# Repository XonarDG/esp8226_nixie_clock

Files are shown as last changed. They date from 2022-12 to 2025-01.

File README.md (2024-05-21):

# esp8266_nixie_clock

Simple Nixie Clock with an ESP8266 development board

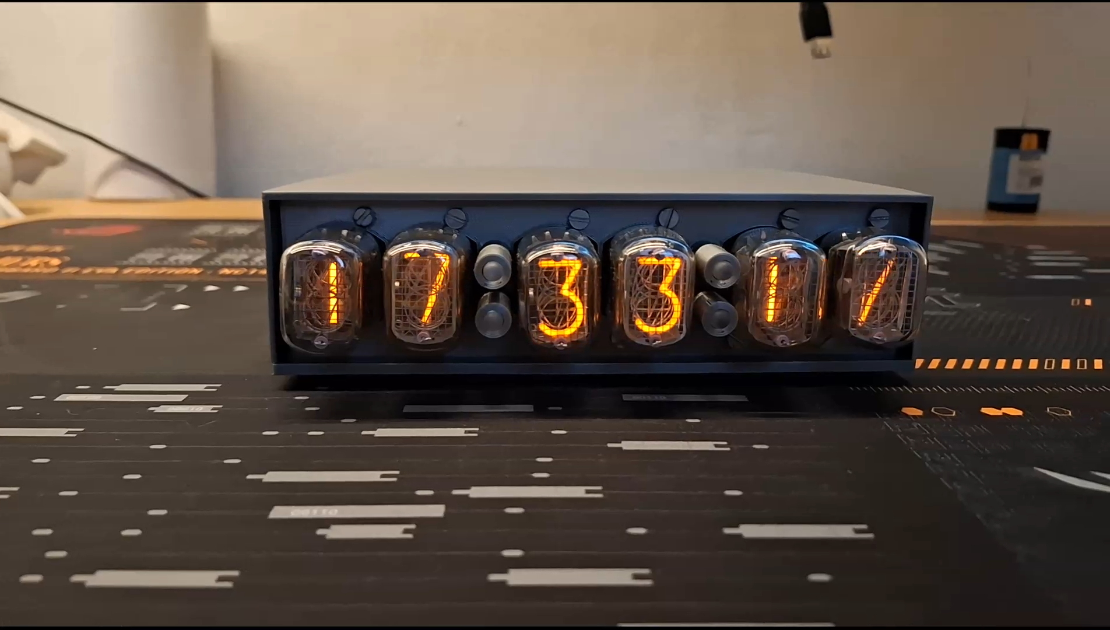
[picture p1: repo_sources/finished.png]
picture of the completed project


## Info

This is a small project for a simple nixie clock using a ESP8266 development board. **WIP! USE AS REFERENCE ONLY!**

## Why?
Like many others, I've fallen for the look of nixies way before this project began. At the time I thought I wasn't capable of a project like this, but in late 2021 I made my first prototype using MH74141 and Tesla ZM1020 nixies. It was rough, didn't work properly and was on a protoboard, but it motivated me into doing more.

In 2024 I made the decision to make this my high school graduation project and this is what came out of it. It still has rough edges here and there, but it works, and it has a somewhat complete enclosure.

At this point I thought it would be a nice touch making the project publicly available. That said its far from done, and I would not recommend making this project on your own.

## Parts
Name | Designation | #
--- | --- | ---
MCU | Wemos D1 Mini | 1
RTC module | generic DS3231 | 1
Shift Register | 74HC595 | 3
Cathode transistors | MPSA42 | 10
Anode optoucouplers | TLP627 | 6
Voltage Regulator | AMS1117 3.3 | 1
Resistor | various values | 26
Pin header (male) | generic 2.54mm | 21
Pin header (famale) | generic 2.54mm | 46

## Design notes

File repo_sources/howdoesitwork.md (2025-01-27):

# How does it work?
This is a file that will explain how the clock works in detail, I might make this into separate files later on.

## Prequisits
Before we start talking about all the principles that allow this clock to work, its important that we set and define certain properties and goals of this project.

### The goal
The goal of this projct is to make a simple, easily modifiable nixie tube clock. In other words, im gonna try to use as little components as possible, while using ones that are readily available and ones that are easy to work with and allow for further modifications.
### Features and properties
1. 6 digits
* Since I've made a 4 digit clock before, I can tell you that watching the same 4 digits for a minute straight is nothing fun. A added benefit is that we can also show other interesing numbers. 
2. NTP synchronization and RTC
* The most common way of keeping somewhat precise time is by utilizing a RTC module, which keeps time using a dedicated IC powered by a battery (usually a CR2023 or similar). This is, relatively speaking, a accurate way of keeping time, but I personaly find these cheap modules too imprecise. I've measured a time delay of around 7 seconds per day, which isn't perticularly bad, but since we're using 6 digits I thought it would be rather nice to have a clock that would be constantly accurate over long periods of time. This is exactly why I decided that I want to synchronize with an NTP server.
3. Extra IO and simplicity
* Yes, I could've used a cheaper discrete MCU. Yes, I could've used SMD versions of IC's to make the footprint smaller. Of course, but that would make the project unfriendly for anyone wishing to modify it.

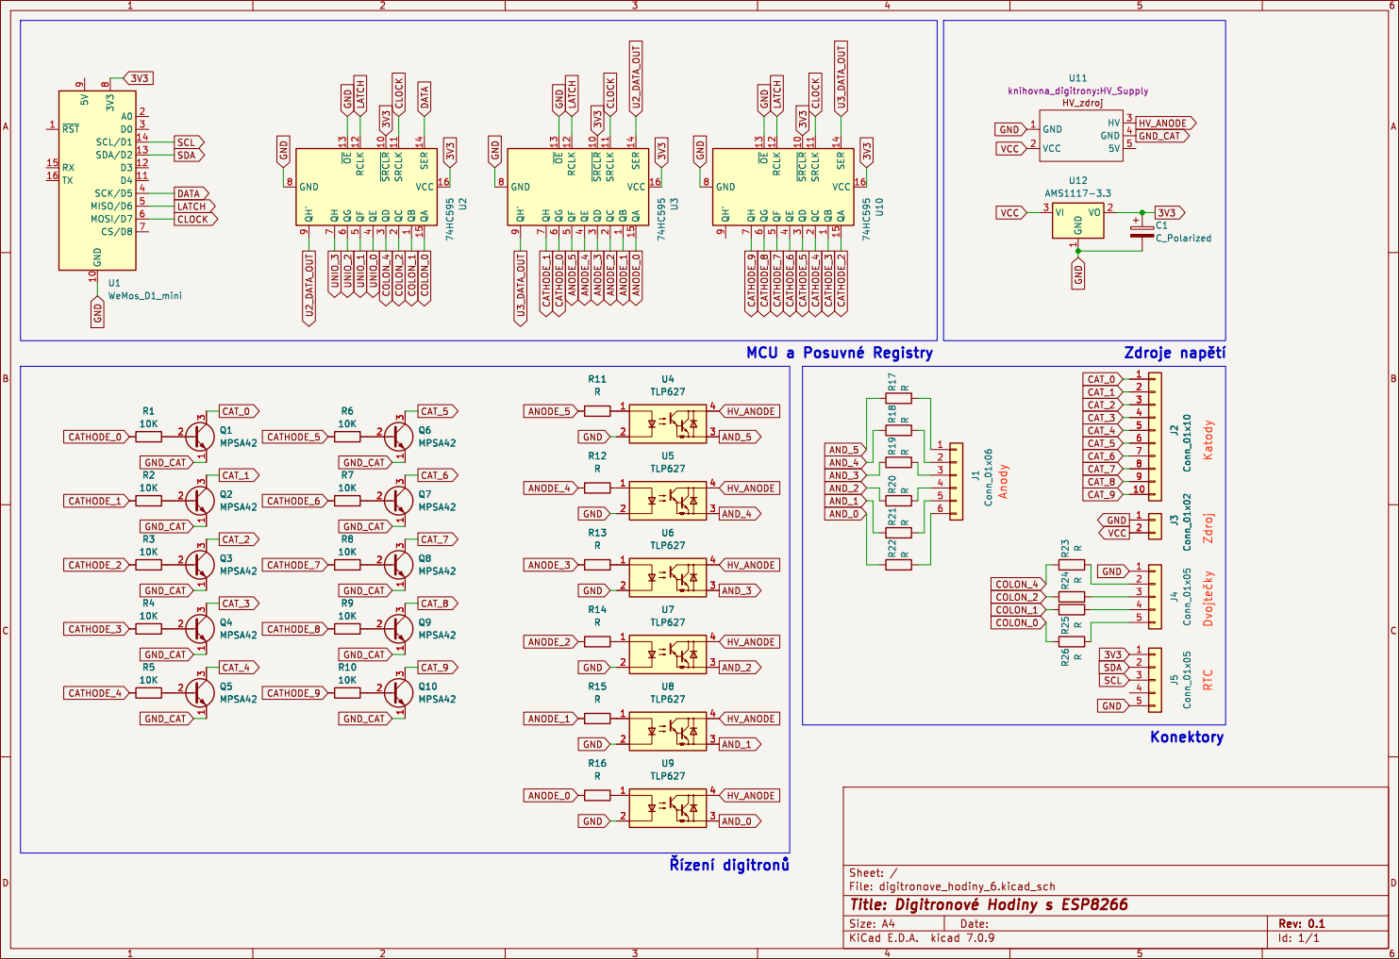
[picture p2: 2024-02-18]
resources/schema.png

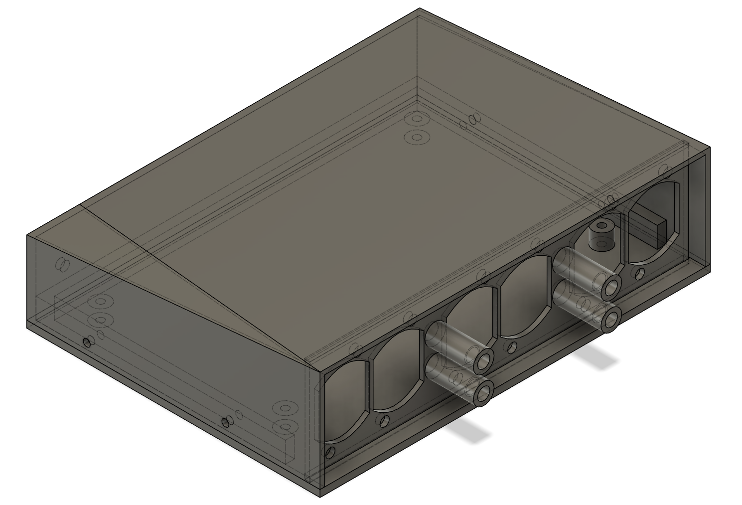
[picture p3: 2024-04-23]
repo_sources/3D_preview.png

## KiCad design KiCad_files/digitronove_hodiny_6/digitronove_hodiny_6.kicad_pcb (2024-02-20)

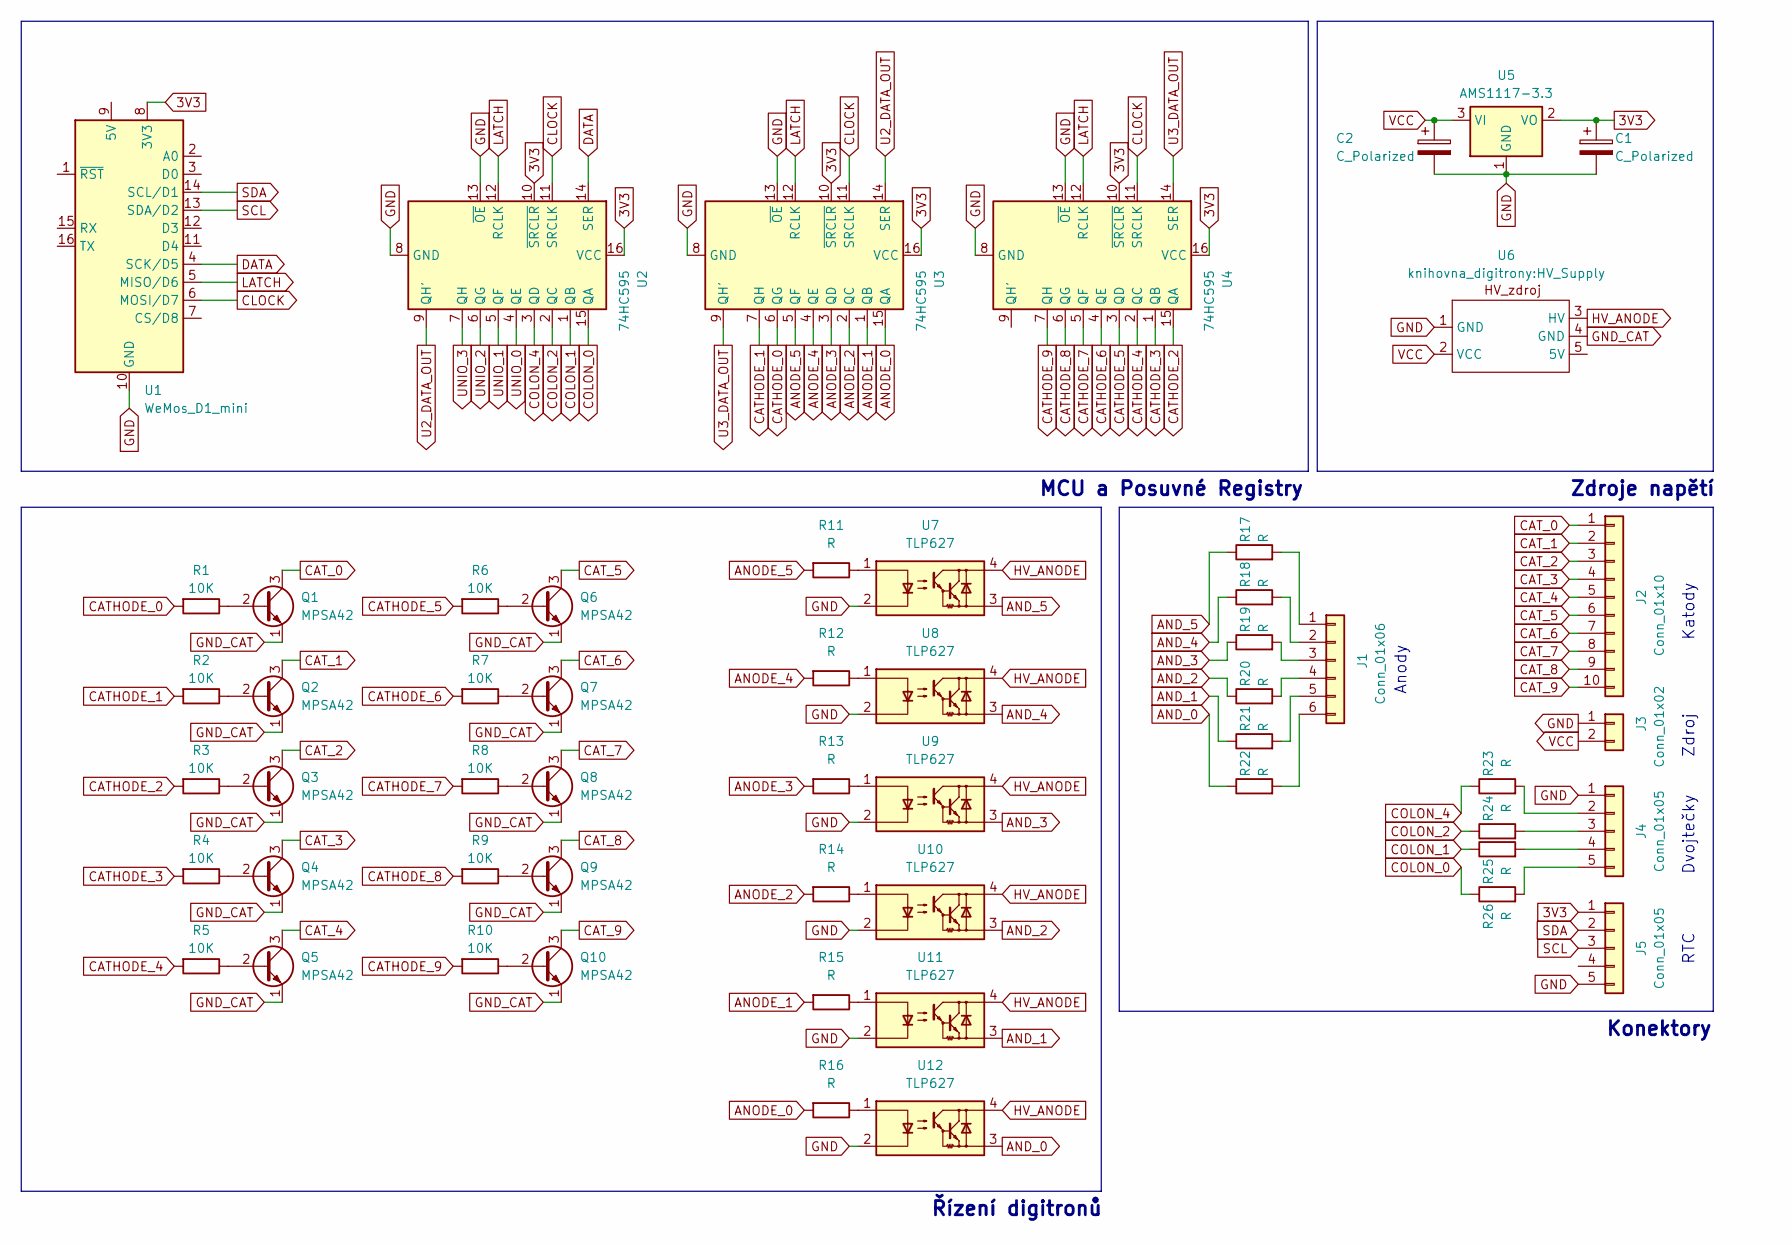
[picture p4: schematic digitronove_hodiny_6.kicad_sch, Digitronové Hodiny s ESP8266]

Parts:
C1, C2: C_Polarized; CP_Radial_Tantal_D5.5mm_P2.50mm
J1: Conn_01x06; PinHeader_1x06_P2.54mm_Vertical
J2: Conn_01x10; PinHeader_1x10_P2.54mm_Vertical
J3: Conn_01x02; PinHeader_1x02_P2.54mm_Vertical
J4, J5: Conn_01x05; PinHeader_1x05_P2.54mm_Vertical
Q1, Q2, Q3, Q4, Q5, Q6, Q7, Q8, Q9, Q10: MPSA42; TO-92_Inline_Wide
R1, R2, R3, R4, R5, R6, R7, R8, R9, R10: 10K; R_Axial_DIN0204_L3.6mm_D1.6mm_P7.62mm_Horizontal
R11, R12, R13, R14, R15, R16, R17, R18, R19, R20, R21, R22, R23, R24, R25, R26: R; R_Axial_DIN0204_L3.6mm_D1.6mm_P7.62mm_Horizontal
U1: WeMos_D1_mini; WEMOS_D1_mini_light
U2, U3, U4: 74HC595; DIP-16_W7.62mm
U5: AMS1117-3.3; SOT-223-3_TabPin2
U6: HV_Supply
U7, U8, U9, U10, U11, U12: TLP627; DIP-4_W7.62mm

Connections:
3V3: C1.1, J5.1, U1.8 (3V3), U2.10 (~SRCLR), U2.16 (VCC), U3.10 (~SRCLR), U3.16 (VCC), U4.10 (~SRCLR), U4.16 (VCC), U5.2 (VO)
AND_0: R22.1, U12.3
AND_1: R21.1, U11.3
AND_2: R20.1, U10.3
AND_3: R19.1, U9.3
AND_4: R18.1, U8.3
AND_5: R17.1, U7.3
ANODE_0: R16.2, U3.15 (QA)
ANODE_1: R15.2, U3.1 (QB)
ANODE_2: R14.2, U3.2 (QC)
ANODE_3: R13.2, U3.3 (QD)
ANODE_4: R12.2, U3.4 (QE)
ANODE_5: R11.2, U3.5 (QF)
CATHODE_0: R1.2, U3.6 (QG)
CATHODE_1: R2.2, U3.7 (QH)
CATHODE_2: R3.2, U4.15 (QA)
CATHODE_3: R4.2, U4.1 (QB)
CATHODE_4: R5.2, U4.2 (QC)
CATHODE_5: R6.2, U4.3 (QD)
CATHODE_6: R7.2, U4.4 (QE)
CATHODE_7: R8.2, U4.5 (QF)
CATHODE_8: R9.2, U4.6 (QG)
CATHODE_9: R10.2, U4.7 (QH)
CAT_0: J2.1, Q1.3 (C)
CAT_1: J2.2, Q2.3 (C)
CAT_2: J2.3, Q3.3 (C)
CAT_3: J2.4, Q4.3 (C)
CAT_4: J2.5, Q5.3 (C)
CAT_5: J2.6, Q6.3 (C)
CAT_6: J2.7, Q7.3 (C)
CAT_7: J2.8, Q8.3 (C)
CAT_8: J2.9, Q9.3 (C)
CAT_9: J2.10, Q10.3 (C)
CLOCK: U1.6 (MOSI/D7), U2.11 (SRCLK), U3.11 (SRCLK), U4.11 (SRCLK)
COLON_0: R26.1, U2.15 (QA)
COLON_1: R25.1, U2.1 (QB)
COLON_2: R24.1, U2.2 (QC)
COLON_4: R23.1, U2.3 (QD)
DATA: U1.4 (SCK/D5), U2.14 (SER)
GND: C1.2, C2.2, J3.1, J4.1, J5.5, U1.10 (GND), U2.8 (GND), U2.13 (~OE), U3.8 (GND), U3.13 (~OE), U4.8 (GND), U4.13 (~OE), U5.1 (GND), U6.1 (GND), U7.2, U8.2, U9.2, U10.2, U11.2, U12.2
GND_CAT: Q1.1 (E), Q2.1 (E), Q3.1 (E), Q4.1 (E), Q5.1 (E), Q6.1 (E), Q7.1 (E), Q8.1 (E), Q9.1 (E), Q10.1 (E), U6.4 (GND)
HV_ANODE: U6.3 (HV), U7.4, U8.4, U9.4, U10.4, U11.4, U12.4
LATCH: U1.5 (MISO/D6), U2.12 (RCLK), U3.12 (RCLK), U4.12 (RCLK)
unnamed: J1.1, R17.2
unnamed: J1.2, R18.2
unnamed: J1.3, R19.2
unnamed: J1.4, R20.2
unnamed: J1.5, R21.2
unnamed: J1.6, R22.2
unnamed: J4.2, R23.2
unnamed: J4.3, R24.2
unnamed: J4.4, R25.2
unnamed: J4.5, R26.2
unnamed: Q1.2 (B), R1.1
unnamed: Q2.2 (B), R2.1
unnamed: Q3.2 (B), R3.1
unnamed: Q4.2 (B), R4.1
unnamed: Q5.2 (B), R5.1
unnamed: Q6.2 (B), R6.1
unnamed: Q7.2 (B), R7.1
unnamed: Q8.2 (B), R8.1
unnamed: Q9.2 (B), R9.1
unnamed: Q10.2 (B), R10.1
unnamed: R11.1, U7.1
unnamed: R12.1, U8.1
unnamed: R13.1, U9.1
unnamed: R14.1, U10.1
unnamed: R15.1, U11.1
unnamed: R16.1, U12.1
SCL: J5.3, U1.13 (SDA/D2)
SDA: J5.2, U1.14 (SCL/D1)
U2_DATA_OUT: U2.9 (QH'), U3.14 (SER)
U3_DATA_OUT: U3.9 (QH'), U4.14 (SER)
UNIO_0: U2.4 (QE)
UNIO_1: U2.5 (QF)
UNIO_2: U2.6 (QG)
UNIO_3: U2.7 (QH)
VCC: C2.1, J3.2, U5.3 (VI), U6.2 (VCC)

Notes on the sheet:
Zdroje napětí
RTC
Anody
Řízení digitronů
Zdroj
Konektory
Katody
Dvojtečky
MCU a Posuvné Registry

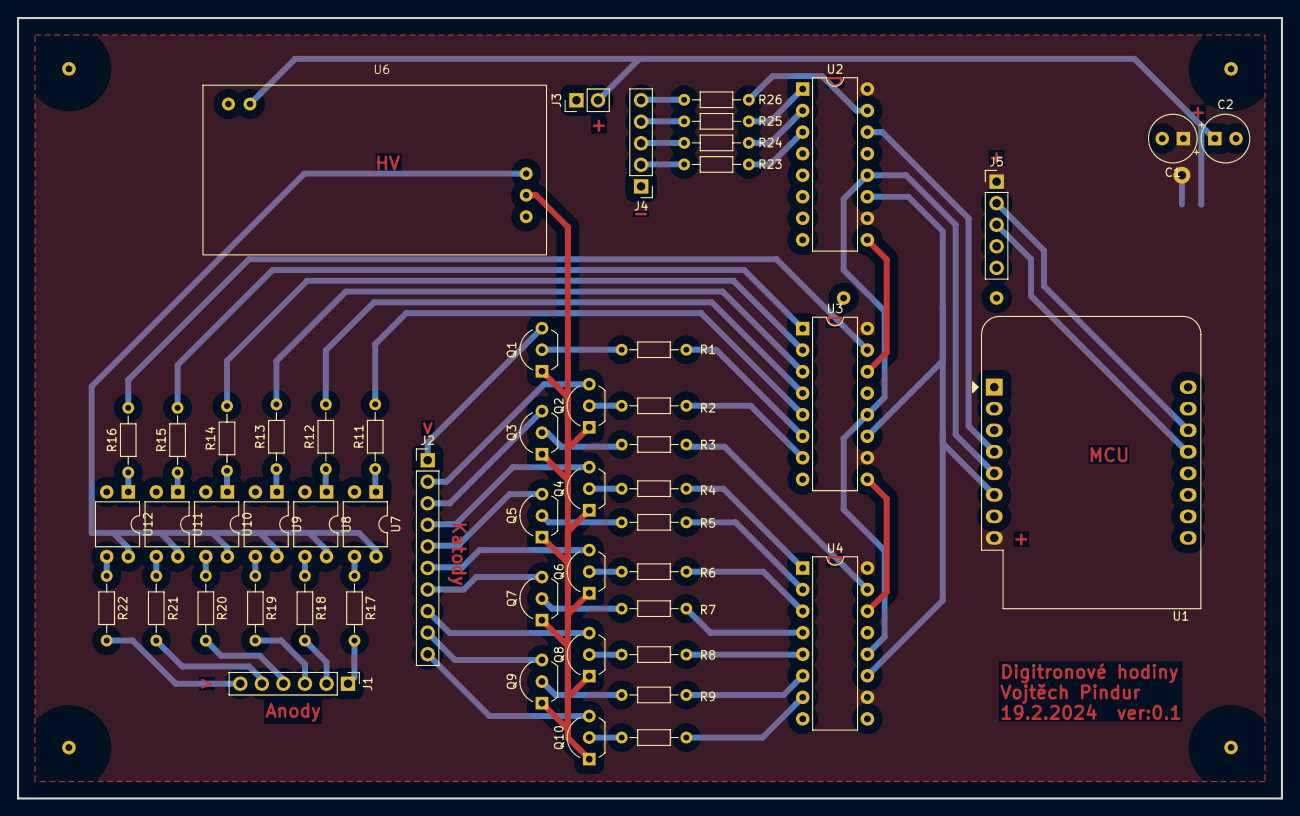
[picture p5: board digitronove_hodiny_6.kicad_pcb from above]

Board: 2 copper layers, 149.0 x 92.0 mm, 55 parts (1 on the bottom side), 74 nets.

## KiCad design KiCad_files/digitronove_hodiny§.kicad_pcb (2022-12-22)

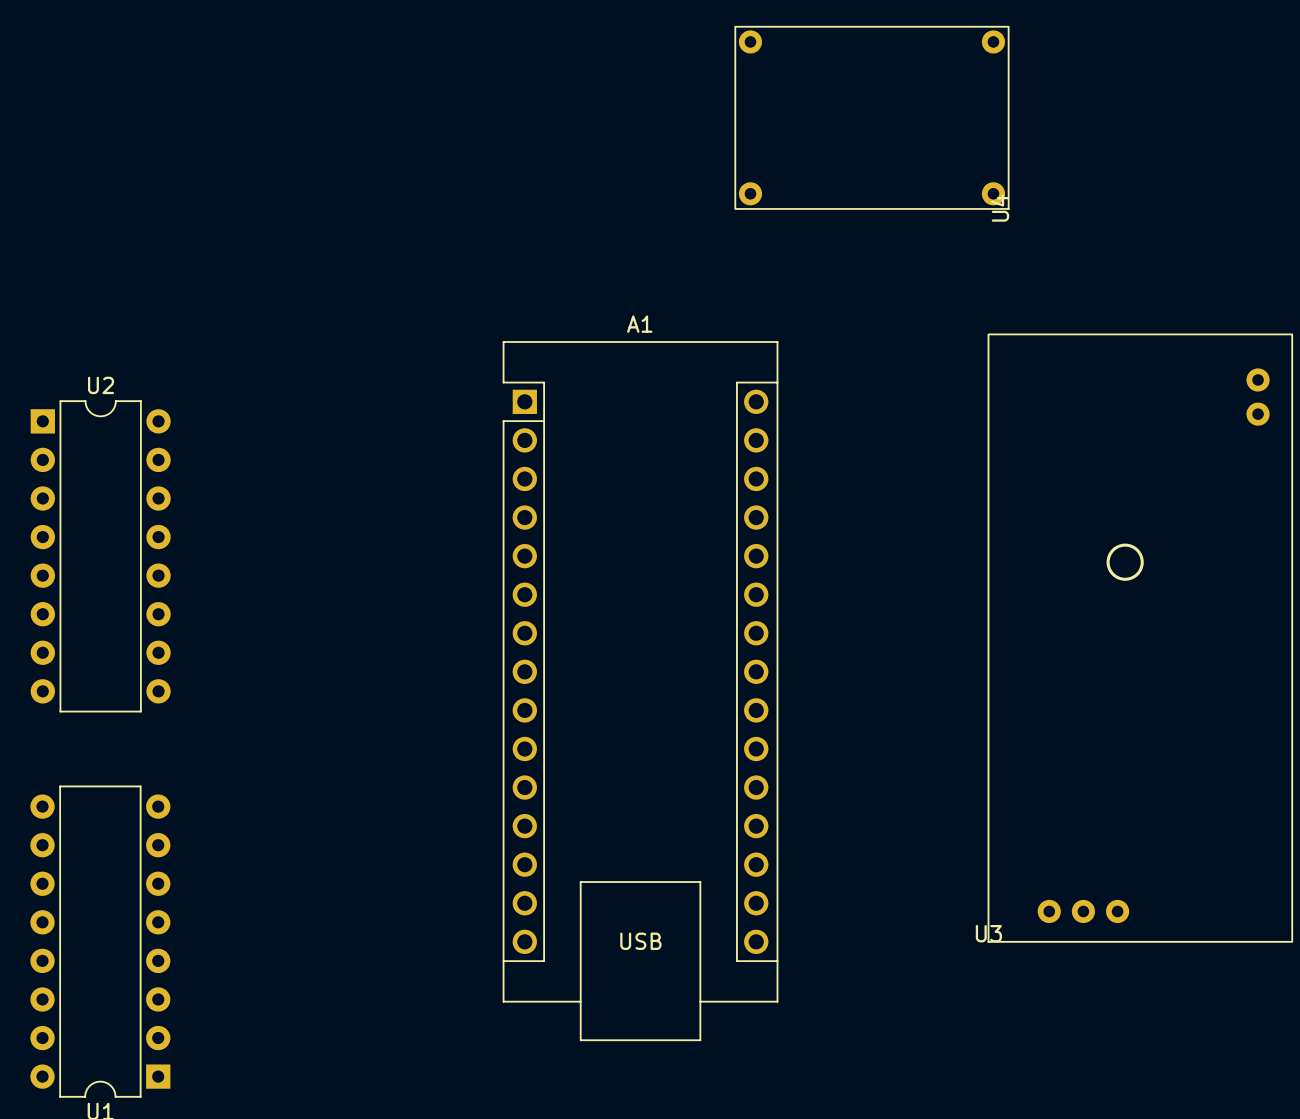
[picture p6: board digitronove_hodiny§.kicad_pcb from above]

Board: 2 copper layers, 5 parts (0 on the bottom side), 12 nets, no tracks yet.

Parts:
A1: Arduino_Nano_Every; Arduino_Nano
U1: 74141; DIP-16_W7.62mm
U2: TLP627-4; DIP-16_W7.62mm
U3: HV_supply_module
U4: Mini360; DC-DC_MINI_360_Step_down

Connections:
GND: A1.4 (GND), A1.29 (GND), U1.12 (GND), U2.2, U2.4, U2.6, U2.8, U4.1 (GND)
unnamed: A1.7 (D4), U2.3
unnamed: A1.8 (D5), U2.5
unnamed: A1.9 (D6), U2.7
unnamed: A1.10 (D7), U1.3 (A)
unnamed: A1.11 (D8), U1.6 (B)
unnamed: A1.12 (D9), U1.7 (C)
unnamed: A1.13 (D10), U1.4 (D)
unnamed: A1.30 (VIN), U4.3 (VOUT)
unnamed: A1.6 (D3), U2.1
unnamed: U2.10, U2.12, U2.14, U2.16, U3.3 (HV)
VCC: A1.27 (+5V), U1.5 (VCC), U3.5 (VCC), U4.2 (VCC)

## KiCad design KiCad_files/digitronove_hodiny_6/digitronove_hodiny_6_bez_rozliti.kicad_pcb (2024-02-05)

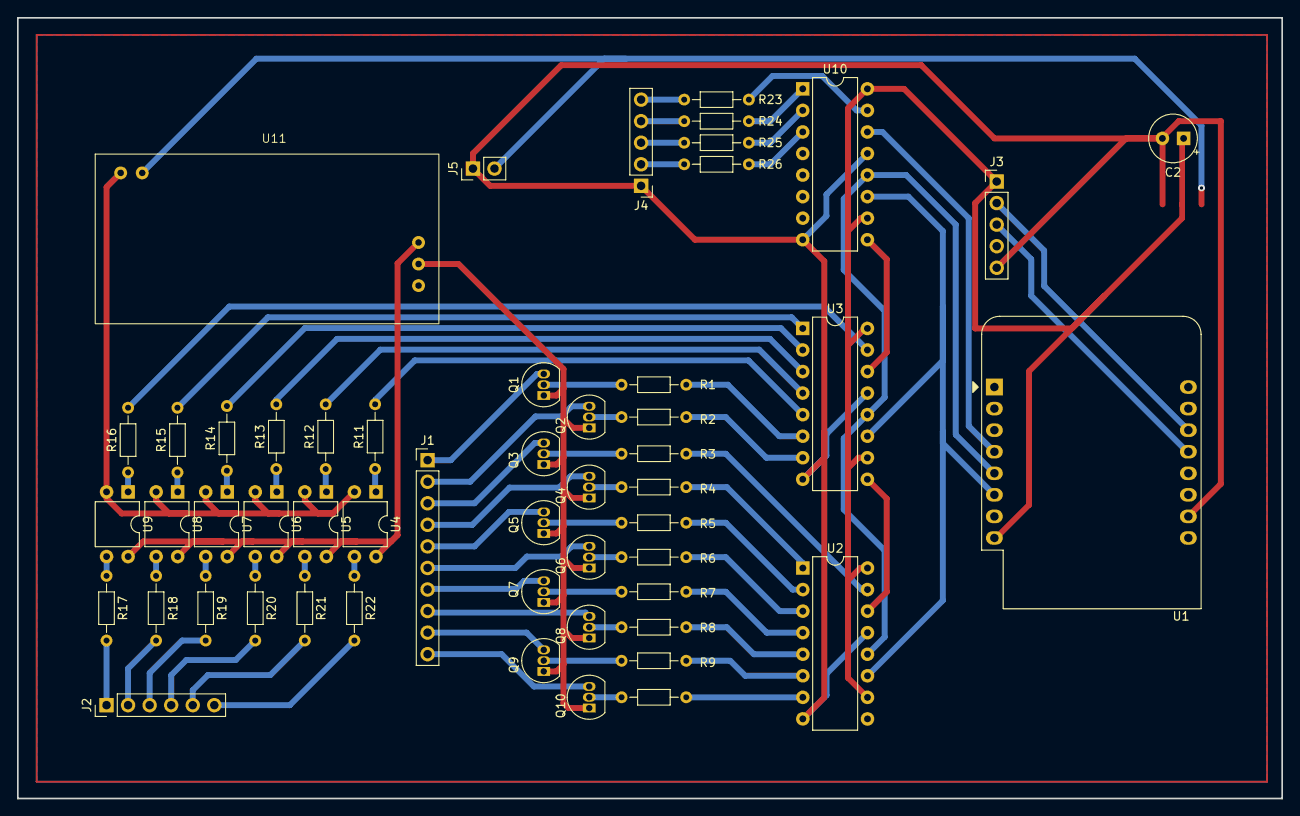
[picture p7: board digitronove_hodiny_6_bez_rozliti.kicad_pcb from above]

Board: 2 copper layers, 149.0 x 92.0 mm, 54 parts (1 on the bottom side), 74 nets.

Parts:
C2: C_Polarized; CP_Radial_Tantal_D5.5mm_P2.50mm
J1: Nixie_CATHODES; PinHeader_1x10_P2.54mm_Vertical
J2: Nixie_ANODES; PinHeader_1x06_P2.54mm_Vertical
J3, J4: Conn_01x05; PinHeader_1x05_P2.54mm_Vertical
J5: Conn_01x02; PinHeader_1x02_P2.54mm_Vertical
Q1, Q2, Q3, Q4, Q5, Q6, Q7, Q8, Q9, Q10: MPSA42; TO-92_Inline
R1, R2, R3, R4, R5, R6, R7, R8, R9, R10: 10K; R_Axial_DIN0204_L3.6mm_D1.6mm_P7.62mm_Horizontal
R11, R12, R13, R14, R15, R16, R17, R18, R19, R20, R21, R22, R23, R24, R25, R26: R; R_Axial_DIN0204_L3.6mm_D1.6mm_P7.62mm_Horizontal
U1: WeMos_D1_mini; WEMOS_D1_mini_light
U2, U3, U10: 74HC595; DIP-16_W7.62mm
U4, U5, U6, U7, U8, U9: TLP627; DIP-4_W7.62mm
U11: HV_Supply
U12: AMS1117-3.3; SOT-223-3_TabPin2

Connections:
3V3: C2.1, J3.1, U1.8 (3V3), U2.10 (~SRCLR), U2.16 (VCC), U3.10 (~SRCLR), U3.16 (VCC), U10.10 (~SRCLR), U10.16 (VCC), U12.2 (VO)
AND_0: R17.1, U9.3
AND_1: R18.1, U8.3
AND_2: R19.1, U7.3
AND_3: R20.1, U6.3
AND_4: R21.1, U5.3
AND_5: R22.1, U4.3
ANODE_0: R16.2, U3.15 (QA)
ANODE_1: R15.2, U3.1 (QB)
ANODE_2: R14.2, U3.2 (QC)
ANODE_3: R13.2, U3.3 (QD)
ANODE_4: R12.2, U3.4 (QE)
ANODE_5: R11.2, U3.5 (QF)
CATHODE_0: R1.2, U3.6 (QG)
CATHODE_1: R2.2, U3.7 (QH)
CATHODE_2: R3.2, U2.15 (QA)
CATHODE_3: R4.2, U2.1 (QB)
CATHODE_4: R5.2, U2.2 (QC)
CATHODE_5: R6.2, U2.3 (QD)
CATHODE_6: R7.2, U2.4 (QE)
CATHODE_7: R8.2, U2.5 (QF)
CATHODE_8: R9.2, U2.6 (QG)
CATHODE_9: R10.2, U2.7 (QH)
CAT_0: J1.1, Q1.3 (C)
CAT_1: J1.2, Q2.3 (C)
CAT_2: J1.3, Q3.3 (C)
CAT_3: J1.4, Q4.3 (C)
CAT_4: J1.5, Q5.3 (C)
CAT_5: J1.6, Q6.3 (C)
CAT_6: J1.7, Q7.3 (C)
CAT_7: J1.8, Q8.3 (C)
CAT_8: J1.9, Q9.3 (C)
CAT_9: J1.10, Q10.3 (C)
CLOCK: U1.6 (MOSI/D7), U2.11 (SRCLK), U3.11 (SRCLK), U10.11 (SRCLK)
COLON_0: R23.1, U10.15 (QA)
COLON_1: R24.1, U10.1 (QB)
COLON_2: R25.1, U10.2 (QC)
COLON_4: R26.1, U10.3 (QD)
DATA: U1.4 (SCK/D5), U10.14 (SER)
GND: C2.2, J3.5, J4.1, J5.1, U1.10 (GND), U2.8 (GND), U2.13 (~OE), U3.8 (GND), U3.13 (~OE), U4.2, U5.2, U6.2, U7.2, U8.2, U9.2, U10.8 (GND), U10.13 (~OE), U11.1 (GND), U12.1 (GND)
GND_CAT: Q1.1 (E), Q2.1 (E), Q3.1 (E), Q4.1 (E), Q5.1 (E), Q6.1 (E), Q7.1 (E), Q8.1 (E), Q9.1 (E), Q10.1 (E), U11.4 (GND)
HV_ANODE: U4.4, U5.4, U6.4, U7.4, U8.4, U9.4, U11.3 (HV)
LATCH: U1.5 (MISO/D6), U2.12 (RCLK), U3.12 (RCLK), U10.12 (RCLK)
unnamed: J2.1, R17.2
unnamed: J2.2, R18.2
unnamed: J2.3, R19.2
unnamed: J2.4, R20.2
unnamed: J2.5, R21.2
unnamed: J2.6, R22.2
unnamed: J4.2, R26.2
unnamed: J4.3, R25.2
unnamed: J4.4, R24.2
unnamed: J4.5, R23.2
unnamed: Q1.2 (B), R1.1
unnamed: Q2.2 (B), R2.1
unnamed: Q3.2 (B), R3.1
unnamed: Q4.2 (B), R4.1
unnamed: Q5.2 (B), R5.1
unnamed: Q6.2 (B), R6.1
unnamed: Q7.2 (B), R7.1
unnamed: Q8.2 (B), R8.1
unnamed: Q9.2 (B), R9.1
unnamed: Q10.2 (B), R10.1
unnamed: R11.1, U4.1
unnamed: R12.1, U5.1
unnamed: R13.1, U6.1
unnamed: R14.1, U7.1
unnamed: R15.1, U8.1
unnamed: R16.1, U9.1
SCL: J3.3, U1.13 (SDA/D2)
SDA: J3.2, U1.14 (SCL/D1)
U2_DATA_OUT: U3.14 (SER), U10.9 (QH')
U3_DATA_OUT: U2.14 (SER), U3.9 (QH')
VCC: J5.2, U11.2 (VCC), U12.3 (VI)

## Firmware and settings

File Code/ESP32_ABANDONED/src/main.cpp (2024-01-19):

#include <Arduino.h>
#include <RTClib.h>
#include <SPI.h>
#include <Wire.h>
#include <WiFiUdp.h>
#include <WiFi.h>
#include <Update.h>
#include "time.h"
#include "arduino_secrets.h"

//declaring optocoupler outputs
#define TH 13
#define H 12
#define TM 14
#define M 27

//declaring 74141's pins
#define A 33
#define B 26
#define C 32
#define D 25

//colon LED's
#define COLON_BOTTOM 19
#define COLON_TOP 18

//I2C
#define SDA 22
#define SCL 23

//declaring the RTC
RTC_DS3231 rtc;


//NTP server config variables
long gmtoffset_sec = 3600; 
int daylightoffset_sec = 3600;
const char* ntpserver = "0.cz.pool.ntp.org";

//operation config variables
const long multiplex_timing = 2;
bool doonceswitch = true;
int nextrtcupdate = 0;
int wifitimeout = 0;
bool connection_fault = false;

void setup() 
{
  Wire.begin(SDA,SCL); //starts I2C communication on defined GPIO
  rtc.begin(); //starts communication with the RTC module
  Serial.begin(9600); //debug
  rtc.adjust(DateTime(F(__DATE__), F(__TIME__))); //updates the RTC's time according to the time of the code compilation
  

  //declaring pin modes
  pinMode(TH, OUTPUT);
  pinMode(H, OUTPUT);
  pinMode(TM, OUTPUT);
  pinMode(M, OUTPUT);
  pinMode(A, OUTPUT);
  pinMode(B, OUTPUT);
  pinMode(C, OUTPUT);
  pinMode(D, OUTPUT);
  pinMode(COLON_BOTTOM, OUTPUT);
  pinMode(COLON_TOP, OUTPUT);

  //settings all output pins LOW for a good measure
  digitalWrite(TH, LOW);
  digitalWrite(H, LOW);
  digitalWrite(TM, LOW);
  digitalWrite(M, LOW);
  digitalWrite(A, LOW);
  digitalWrite(B, LOW);
  digitalWrite(C, LOW);
  digitalWrite(D, LOW);
  digitalWrite(COLON_BOTTOM, LOW);
  digitalWrite(COLON_TOP, LOW);


}

void WriteNumber(int number)
{
  //this method contains the truth table for the MH/SN74141 and sets the pins according to given number
  //if needed this can be rewritten to work with other Nixie Drivers 
  switch (number) {
    case 0:
      digitalWrite(A, LOW);
      digitalWrite(B, LOW);
      digitalWrite(C, LOW);
      digitalWrite(D, LOW);
      break;
    case 9:
      digitalWrite(A, LOW);
      digitalWrite(B, HIGH);
      digitalWrite(C, LOW);
      digitalWrite(D, HIGH);
      break;
    case 8:
      digitalWrite(A, LOW);
      digitalWrite(B, LOW);
      digitalWrite(C, LOW);
      digitalWrite(D, HIGH);
      break;
    case 7:
      digitalWrite(A, HIGH);
      digitalWrite(B, HIGH);
      digitalWrite(C, HIGH);
      digitalWrite(D, LOW);
      break;
    case 6:
      digitalWrite(A, LOW);
      digitalWrite(B, HIGH);
      digitalWrite(C, HIGH);
      digitalWrite(D, LOW);
      break;
    case 5:
      digitalWrite(A, HIGH);
      digitalWrite(B, LOW);
      digitalWrite(C, HIGH);
      digitalWrite(D, LOW);
      break;
    case 4:
      digitalWrite(A, LOW);
      digitalWrite(B, LOW);
      digitalWrite(C, HIGH);
      digitalWrite(D, LOW);
      break;
    case 3:
      digitalWrite(A, HIGH);
      digitalWrite(B, HIGH);
      digitalWrite(C, LOW);
      digitalWrite(D, LOW);
      break;
    case 2:
      digitalWrite(A, LOW);
      digitalWrite(B, HIGH);
      digitalWrite(C, LOW);
      digitalWrite(D, LOW);
      break;
    case 1:
      digitalWrite(A, HIGH);
      digitalWrite(B, LOW);
      digitalWrite(C, LOW);
      digitalWrite(D, LOW);
      break;
  }
}
void MultiPlex(int first_number, int second_number, int third_number, int forth_number)

{
  //this method handles the multiplexing of the nixies, the delays are there to slow the ESP32 down, since at full speed, the MH74141 is not able to keep up with the ESP32
  //eventually this has to be rewritten to use millis() instead of delay()
  WriteNumber(first_number);
  digitalWrite(TH, HIGH);
  delay(multiplex_timing);
  digitalWrite(TH, LOW);
  delay(1);

  WriteNumber(second_number);
  digitalWrite(H, HIGH);
  delay(multiplex_timing);
  digitalWrite(H, LOW);
  delay(1);

  WriteNumber(third_number);
  digitalWrite(TM, HIGH);
  delay(multiplex_timing);
  digitalWrite(TM, LOW);
  delay(1);

  WriteNumber(forth_number);
  digitalWrite(M, HIGH);
  delay(multiplex_timing);
  digitalWrite(M, LOW);
  delay(1);
}

void Colon(int unixtime)
{
  //this method operates the colon, using the function "%" (modulo) to determine if the number is even or odd
  //in the future this method will be changed to allow individual control over the LED's as to allow for signaling faults
  if (connection_fault == true)
  {
      if (unixtime % 2 == 0)
  {
    digitalWrite(COLON_BOTTOM, HIGH);
    digitalWrite(COLON_TOP, HIGH);
  }
  else
  {
    digitalWrite(COLON_BOTTOM, LOW);
    digitalWrite(COLON_TOP, HIGH);  
  }
  }
  else
  {
    if (unixtime % 2 == 0)
  {
    digitalWrite(COLON_BOTTOM, HIGH);
    digitalWrite(COLON_TOP, HIGH);
  }
  else
  {
    digitalWrite(COLON_BOTTOM, LOW);
    digitalWrite(COLON_TOP, LOW);  
  }
  }  
}
void ShowDate(int day, int month)
{
  //not used currently
  int TenDay = (day / 10) % 10;         
  int Day = (day % 10);
  int TenMonth = (month / 10) % 10;
  int Month = (month % 10);

  digitalWrite(COLON_BOTTOM, HIGH); 
  MultiPlex(TenDay, Day, TenMonth, Month);
}
void ShowTime(int hour, int minute)
{
  //this method converts the RTC's time output into separate numbers that are then fed to the MultiPlex() method to show the current time
  //the use of modulo is taken from GreatScott's project
  int TenHour = (hour / 10) % 10;         
  int Hour = (hour % 10);
  int TenMinute = (minute / 10) % 10;
  int Minute = (minute % 10);

  MultiPlex(TenHour, Hour, TenMinute, Minute);
}

int GetNTPTime()
{
  //this method connects to Wi-Fi and gets the current NTP time
  DateTime rtctime = rtc.now();
  wifitimeout = rtctime.unixtime();
  WiFi.begin(SECRET_SSID, SECRET_PASS);
  while (WiFi.status() != WL_CONNECTED)
  {
    if (rtctime.unixtime() - wifitimeout > 15)
    {
      return 0;
    }
  }
  configTime(gmtoffset_sec, daylightoffset_sec, ntpserver);
  return 1;
}
void WriteRTC() {
   struct tm timeinfo;
   if(!getLocalTime(&timeinfo)) {
     return;
   }
   rtc.adjust(DateTime(timeinfo.tm_year +1900, timeinfo.tm_mon +1, timeinfo.tm_mday, timeinfo.tm_hour, timeinfo.tm_min, timeinfo.tm_sec));
   WiFi.disconnect();
}
void UpdateRTC(int unixtime, int updateinterval_sec)
{
  if (doonceswitch == true)
  {
    GetNTPTime();
    WriteRTC();
    nextrtcupdate = unixtime + updateinterval_sec;
    doonceswitch = false;
  }

  if (unixtime == nextrtcupdate)
  {
    if (GetNTPTime() == 0)
    {
      connection_fault = true;
      nextrtcupdate = unixtime + updateinterval_sec;
      return;
    }
    WriteRTC();
    nextrtcupdate = unixtime + updateinterval_sec;
  }
}

void loop()
{
  DateTime rtctime = rtc.now();

  if (rtctime.second() >= 55)
  {
    ShowTime(rtctime.minute(), rtctime.second());
  }
  else
  {
    ShowTime(rtctime.hour(), rtctime.minute());
  }
  
  UpdateRTC(rtctime.unixtime(), 21600);
  Colon(rtctime.unixtime());
}

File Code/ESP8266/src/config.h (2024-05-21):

#define SSID "Granik"
#define PASS "dmmq9361"

static long gmtoffset_sec = 3600;                       //timezone info
static int daylightoffset_sec = 3600;                   //summer winter time setting
static const char* ntpserver = "0.cz.pool.ntp.org";     //what NTP server to use, redirect to your local NTP pool (https://www.ntppool.org/)

int animation_interval_sec = random(60, 240);
u_int animation_next;

int ntp_update_interval_sec = 43200;
int ntp_update_interval_failed = 240;
u_int ntp_update_next;

int colon_counter = 0;

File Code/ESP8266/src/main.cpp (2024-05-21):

#include <Arduino.h>
#include <ESP8266WiFi.h>
#include <RTClib.h>
#include <SPI.h>

#include "config.h"

#define DATA D5
#define CLOCK D7
#define LATCH D6

#define SDA D1
#define SCL D2

RTC_DS3231 ds3231;

//integer arrays used as a truth table for the shift registers
int cathode_arr[] = {512,1,2,4,8,16,32,64,128,256,0};
int anode_arr[] = {1,2,4,8,16,32,0};
int colon_arr[] = {0b0000000, 0b00000011, 0b00001100,0b00001010, 0b00000101, 0b00000011, 0b00001100, 0b00001010, 0b00001111};

//shift register data variables
uint8_t shift_reg1;
uint8_t shift_reg2;
uint8_t shift_reg3;
uint8_t shift_reg_null;

//connects to Wi-Fi
void WiFiBegin()
{
  WiFi.begin(SSID, PASS);
}
//defines custom I2C pins, establishes I2C comms with RTC
void RTCBegin()
{
  Wire.begin(SDA, SCL);
  ds3231.begin();
}
//gets NTP time and returns it in DateTime object
DateTime GetNTPTime()
{
  struct tm ntp_time;                                                                                                                       //temporary time struct
  configTime(gmtoffset_sec, daylightoffset_sec, ntpserver);                                                                                 //sets the NTP client
  getLocalTime(&ntp_time);                                                                                                            //gets local time and stores it in ntp_time struct
  DateTime time = DateTime(ntp_time.tm_year+1900, ntp_time.tm_mon+1,
  ntp_time.tm_mday, ntp_time.tm_hour, ntp_time.tm_min, ntp_time.tm_sec);                                                              //inserts tm struct into datetime class (rtc library takes only DateTime)
  return time;
}
//connects to Wi-Fi, gets NTP time, updates RTC, disconnects from Wi-Fi
void TimeSync()
{
  DateTime time = GetNTPTime();
  if (time.hour() == 2 && time.minute() == 0)
  {
    WiFi.disconnect();
    WiFi.mode(WIFI_OFF);
  }
  else
  {
    ds3231.adjust(time);
    WiFi.disconnect();
    WiFi.mode(WIFI_OFF);
  }
}
//handles data sent to shift register
void SendData(uint8_t data1, uint8_t data2, uint8_t data3)
{
  digitalWrite(LATCH, LOW);               //sets the LATCH pin LOW, allows shift registers to read data
  shiftOut(DATA, CLOCK, MSBFIRST, data1); //sends first 8 bits
  shiftOut(DATA, CLOCK, MSBFIRST, data2); 
  shiftOut(DATA, CLOCK, MSBFIRST, data3);
  digitalWrite(LATCH, HIGH);              //sets the LATCH pin HIGH, shift registers now act as memory
}
//multiplexes given data with colon blinking
void Multiplex(int hh, int h, int mm, int m, int ss, int s, int multiplex_delay_micro, int blank_delay_micro)
{  
  int time_arr[] = {hh,h,mm,m,ss,s};                   //array used to access the correct data based on the multiplexing cycle

  for (size_t i = 0; i <= 5; i++)
  {
  
  //simple logic to blink the colons on even numbers
  int set_colons;
  if (s % 2 == 1)
  set_colons = 0;
  else
  set_colons = 8;

  //bit manipulation to give each shift register correct bits
  shift_reg1 = ((cathode_arr[time_arr[i]]) >> 2);                        //takes the first 8 bits from cathode_arr        
  shift_reg2 = (((cathode_arr[time_arr[i]]) << 6) | (anode_arr[i]));     //takes the last 2 bits cathode_arr and all six from anode_arr(which is set by the current multiplex cycle)
  shift_reg3 = colon_arr[set_colons];

  //
  shift_reg_null = (((cathode_arr[time_arr[i]]) << 6) | 0);

  //send data with blanking interval
  SendData(shift_reg1, shift_reg2, shift_reg3);           
  delayMicroseconds(multiplex_delay_micro);
  SendData(shift_reg1, shift_reg_null, 0);   //send blanking data
  delayMicroseconds(blank_delay_micro);                 //length of blanking interval
  }
  colon_counter++;
}
//multiplexes given data with colon blinking
void Multiplex(int hh, int h, int mm, int m, int ss, int s, int colons, int multiplex_delay_micro, int blank_delay_micro)
{  
  int time_arr[] = {hh,h,mm,m,ss,s};                   //array used to access the correct data based on the multiplexing cycle

  for (size_t i = 0; i <= 5; i++)
  {
  
  //simple logic to blink the colons on even numbers
  int set_colons = colons;

  //bit manipulation to give each shift register correct bits
  shift_reg1 = ((cathode_arr[time_arr[i]]) >> 2);                        //takes the first 8 bits from cathode_arr        
  shift_reg2 = (((cathode_arr[time_arr[i]]) << 6) | (anode_arr[i]));     //takes the last 2 bits cathode_arr and all six from anode_arr(which is set by the current multiplex cycle)
  shift_reg3 = colon_arr[set_colons];

  //
  shift_reg_null = (((cathode_arr[time_arr[i]]) << 6) | 0);

  //send data with blanking interval
  SendData(shift_reg1, shift_reg2, shift_reg3);           
  delayMicroseconds(multiplex_delay_micro);
  SendData(shift_reg1, shift_reg_null, 0);   //send blanking data
  delayMicroseconds(blank_delay_micro);                 //length of blanking interval
  }
  colon_counter++;
}
//simple animation
void Animation(u_long speed, u_int repeats)
{
  u_long start_millis = millis();
  for (size_t y = 0; y <= repeats; y++)
  {
    for (size_t i = 0; i < 10;)
    {
      Multiplex(i,i,i,i,i,i,0,1000, 500);
      yield();
      if (millis() - start_millis >= speed)
      {
        start_millis = millis();
        i++;
      }
    }
  }
}

void setup() 
{
  pinMode(DATA, OUTPUT);    
  pinMode(CLOCK, OUTPUT);
  pinMode(LATCH, OUTPUT);

  digitalWrite(DATA,LOW);   
  digitalWrite(CLOCK,LOW);
  digitalWrite(LATCH,LOW);

  SendData(0,0,0);  //sends empty data
  RTCBegin();       //starts RTC module I2C session
  WiFiBegin();      //initiates the connection to WiFi

  DateTime rtc = ds3231.now();
  int unixtime = rtc.unixtime();
  animation_next = unixtime + animation_interval_sec;
  ntp_update_next = unixtime + ntp_update_interval_sec;
}

void loop()
{
  DateTime rtc = ds3231.now();

  int hh = (rtc.hour() / 10) % 10;         
  int h = (rtc.hour() % 10);
  int mm = (rtc.minute() / 10) % 10;
  int m = (rtc.minute() % 10);
  int ss = (rtc.second() / 10) % 10;
  int s = (rtc.second() % 10);

  Multiplex(hh,h,mm,m,ss,s, 1500, 800);
  
  if (rtc.unixtime() >= animation_next)
  {
    Animation(50, 10);
    animation_next = rtc.unixtime() + animation_interval_sec;
  }
  if (rtc.unixtime() >= ntp_update_next)
  {
    WiFiBegin();
    ntp_update_next = rtc.unixtime() + ntp_update_interval_sec;
  }
  if (WiFi.status() == WL_CONNECTED)
  {
    TimeSync();
  }
}

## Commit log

2022-12-18 Created 'KiCad_files' directory and added initital files.
    [digitronove_hodiny§.kicad_pcb, digitronove_hodiny§.kicad_sch]
2022-12-18 Added proprietary symbols and footprints.
2022-12-18 Added KiCad project as a .zip
2022-12-22 Updated .zip containing KiCad project
2022-12-28 Fixed wrong input for AllNumbers method.
    [main.cpp]
2022-12-28 Fixed 'AllNumbers not launching' bug.
    [main.cpp]
2023-01-02 Troubleshooting WIP code, added .stl file.
    Trying to trouble shoot nixie ghosting, added a protoype front panel model to print. More info about in DOCS.md
    [NixieFrontPanel_prototype.stl]
2023-04-19 BIG update!
    Added an entire ESP-32 version of the code that has been rewritten a couple of times. The core is the same but I added a NTP to update the RTC every 6 hours.
2024-01-19 Big update.
    Some development has been done on the project. I'll be abandoning the ESP32 version of the project now, since I've moved to an entire different way of doing things. Read more in README.
2024-01-31 Added new KiCad files.
    [digitronove_hodiny_6.kicad_pcb, digitronove_hodiny_6.kicad_sch, digitronove_hodiny§.kicad_pcb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]
2024-02-05 KiCad PCB and Schema desing update
    Nearly finished PCB desing. Changed the schema according to my breadboard prototype.
    [digitronove_hodiny_6.kicad_pcb, digitronove_hodiny_6.kicad_sch, digitronove_hodiny_6_bez_rozliti.kicad_pcb]
2024-02-06 PCB Update
    [digitronove_hodiny_6.kicad_pcb]
2024-02-12 General changes.
    Removed some unnecesary files, minor changes to PCB design, added a 3D Model directory for future files.
    [NixieFrontPanel_prototype.stl, bom.csv, designators.csv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]
2024-02-18 Created resources directory, EDA files update.
    [digitronove_hodiny_6.kicad_pcb, digitronove_hodiny_6.kicad_sch]
2024-02-20 PCB Design update
    [bom.csv, designators.csv, digitronove_hodiny_6.kicad_pcb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]
2024-03-28 Code and PCB update
2024-05-22 file changes in the kicad section
    [testovaci.kicad_pcb]
2024-05-22 Removed unnecessary files from EDA files.
    [bom.csv, designators.csv, positions.csv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]
